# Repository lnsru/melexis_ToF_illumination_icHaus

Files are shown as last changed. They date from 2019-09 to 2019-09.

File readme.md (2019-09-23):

# Illumination board

This board to be used with time of flight camera. There are interesting chips from Melexis, Infineon, TI and Sony. [My another repository](https://github.com/lnsru/melexis_VGA_ToF_camera "VGA time of flight camera") contains design with Melexis VGA resolution time of flight sensor.

[Higly integrated chip from iC-Haus](http://www.ichaus.de/product/iC-HGP "iC-HGP") was choosen for simpler design. It is specialized high current high speed swich for applications like this one. Buy some from [iC-Haus USA shop.](https://us-shop.ichaus.com/ProductDetails.asp?ProductCode=iC%2DHGP "Buy iC-HGP") 

The design should work with LEDs from Osram and Lumileds. Check datasheet for needed exact voltage, I assume, it will work with 10-12 V power supply.

Following parts are supported:
* Lumileds L1IG-0850000000000 (assembled on prototype board)
* Lumileds L1IG-0940000000000
* Osram SFH 4770S
* Osram SFH 4775S

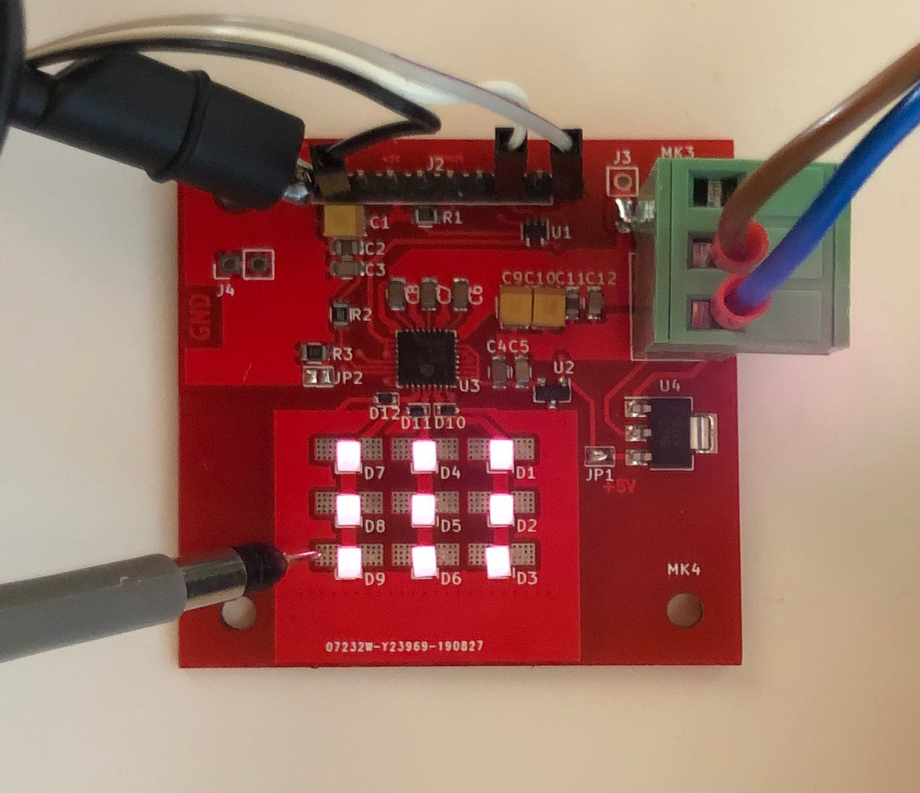
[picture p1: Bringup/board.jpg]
LEDs on


Note: modern phones have infrared filters and can't take nice photos. The glowing red is LED illumination in visible spectrum. The pulses were seen with iPhone 3G and oscilloscope.

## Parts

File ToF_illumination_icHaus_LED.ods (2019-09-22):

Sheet: ToF_illumination_bw
Reference | Quantity | Value | Footprint | Datasheet
C10 C1 | 2 | 10u | Capacitors_SMD:C_1210 | Tantalum!!!
C11 C2 | 2 | 100n | Capacitors_SMD:C_0805 | ~
C12 C3 C5 | 3 | 10n | Capacitors_SMD:C_0805 | ~
C4 C6 C7 C8 | 4 | 1u | Capacitors_SMD:C_0805 | ~
C9 | 1 | 100u | Capacitors_SMD:C_1210 | ~
D12 D11 D10 | 3 | uClamp1201H | Diodes_SMD:D_SOD-523 | https://eu.mouser.com/ProductDetail/Semtech/UCLAMP1201HTCT | UCLAMP1201H.TCT
D8 D7 D9 D5 D4 D6 D2 D1 D3 | 9 | LED | myFootprints:LuxeonIR2720_singlePad | https://eu.mouser.com/ProductDetail/Lumileds/L1IG-0850000000000 | L1IG-0850000000000
J1 | 1 | Screw_Terminal_01x02 | Connectors_Terminal_Blocks:TerminalBlock_bornier-2_P5.08mm | ~
J2 | 1 | Conn_01x10 | Pin_Headers:Pin_Header_Straight_1x10_Pitch2.54mm | ~
J4 J3 | 2 | Conn_01x02 | Pin_Headers:Pin_Header_Straight_1x02_Pitch2.54mm | ~
JP1 JP2 | 2 | SolderJumper_2_Open | Connectors:GS2 | ~
MK1 MK2 MK3 MK4 | 4 | Mounting_Hole | Mounting_Holes:MountingHole_3.2mm_M3_ISO7380
R1 | 1 | 10k | Resistors_SMD:R_0805 | ~
R2 | 1 | 7.5k | Resistors_SMD:R_0805 | ~
R3 | 1 | 3.32k | Resistors_SMD:R_0805 | ~
U1 | 1 | SN74AUP1T34DCK | TO_SOT_Packages_SMD:SOT-353_SC-70-5 | http://www.ti.com/lit/ds/symlink/sn74aup1t34.pdf
U2 | 1 | MCP1541-TT | TO_SOT_Packages_SMD:SOT-23 | http://ww1.microchip.com/downloads/en/devicedoc/21653b.pdf
U3 | 1 | iC-HGP | myFootprints:QFN_32_5x5mm_0.5mm_thermal | https://ichaus.de/upload/pdf/HGP_datasheet_A2en.pdf
U4 | 1 | LM2937xT | TO_SOT_Packages_SMD:SOT-223 | http://www.ti.com/lit/ds/symlink/lm2937.pdf | LM2937IMP-5.0/NOPB

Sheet: ToF_illumination_icHaus_LED
Reference | Quantity | Value | Footprint | Datasheet
C10 C1 | 2 | 10u | Capacitors_SMD:C_1210 | Tantalum!!!
C11 C2 | 2 | 100n | Capacitors_SMD:C_0805 | ~
C12 C3 C5 | 3 | 10n | Capacitors_SMD:C_0805 | ~
C4 C6 C7 C8 | 4 | 1u | Capacitors_SMD:C_0805 | ~
C9 | 1 | 100u | Capacitors_SMD:C_1210 | ~
D12 D11 D10 | 3 | uClamp1201H | Diodes_SMD:D_SOD-523 | https://eu.mouser.com/ProductDetail/Semtech/UCLAMP1201HTCT | UCLAMP1201H.TCT
D8 D7 D9 D5 D4 D6 D2 D1 D3 | 9 | LED | myFootprints:LuxeonIR2720_singlePad | https://eu.mouser.com/ProductDetail/Lumileds/L1IG-0850000000000 | L1IG-0850000000000
J1 | 1 | Screw_Terminal_01x02 | Connectors_Terminal_Blocks:TerminalBlock_bornier-2_P5.08mm | ~
J2 | 1 | Conn_01x10 | Pin_Headers:Pin_Header_Straight_1x10_Pitch2.54mm | ~
J4 J3 | 2 | Conn_01x02 | Pin_Headers:Pin_Header_Straight_1x02_Pitch2.54mm | ~
JP1 JP2 | 2 | SolderJumper_2_Open | Connectors:GS2 | ~
MK1 MK2 MK3 MK4 | 4 | Mounting_Hole | Mounting_Holes:MountingHole_3.2mm_M3_ISO7380
R1 | 1 | 10k | Resistors_SMD:R_0805 | ~
R2 | 1 | 7.5k | Resistors_SMD:R_0805 | ~
R3 | 1 | 3.32k | Resistors_SMD:R_0805 | ~
U1 | 1 | SN74AUP1T34DCK | TO_SOT_Packages_SMD:SOT-353_SC-70-5 | http://www.ti.com/lit/ds/symlink/sn74aup1t34.pdf
U2 | 1 | MCP1541-TT | TO_SOT_Packages_SMD:SOT-23 | http://ww1.microchip.com/downloads/en/devicedoc/21653b.pdf
U3 | 1 | iC-HGP | myFootprints:QFN_32_5x5mm_0.5mm_thermal | https://ichaus.de/upload/pdf/HGP_datasheet_A2en.pdf
U4 | 1 | LM2937xT | TO_SOT_Packages_SMD:SOT-223 | http://www.ti.com/lit/ds/symlink/lm2937.pdf | LM2937IMP-5.0/NOPB

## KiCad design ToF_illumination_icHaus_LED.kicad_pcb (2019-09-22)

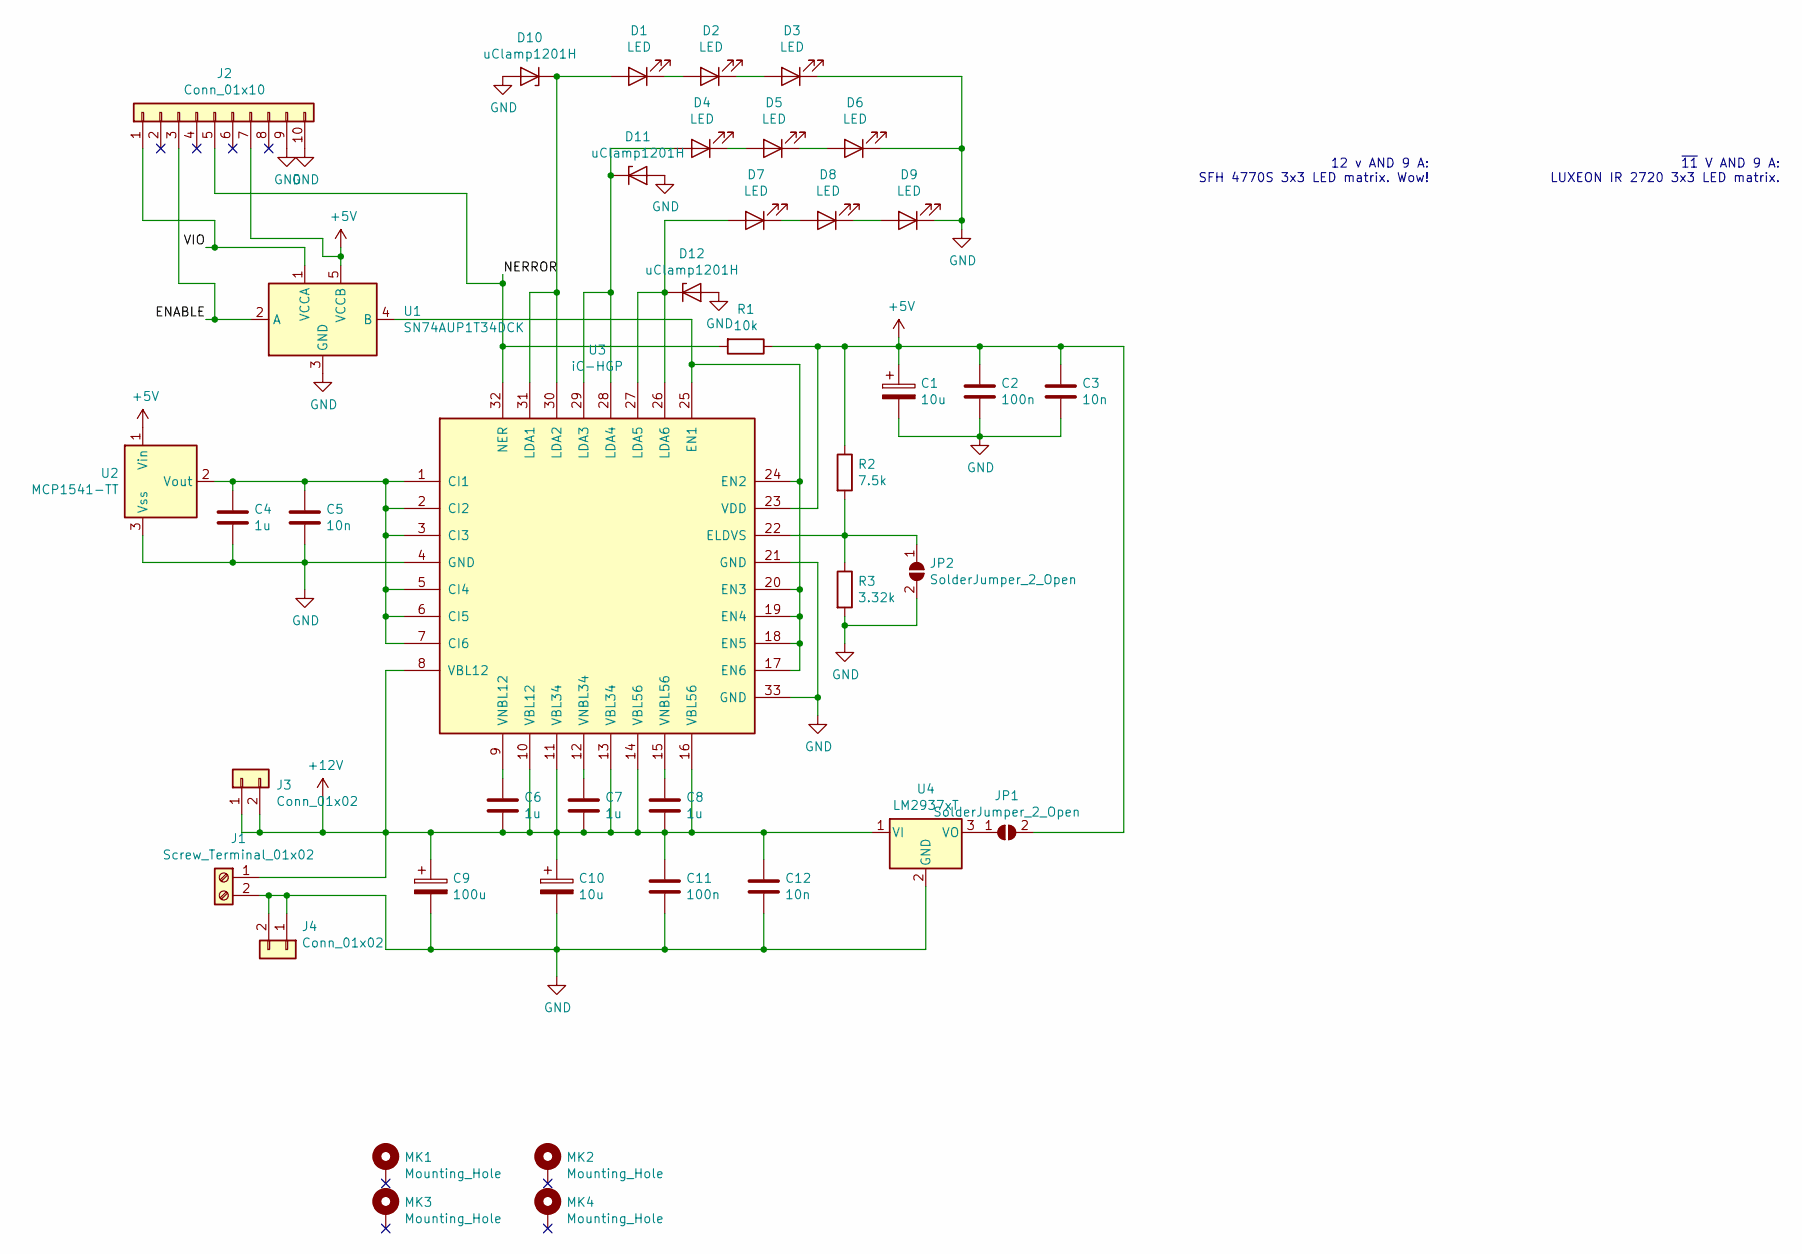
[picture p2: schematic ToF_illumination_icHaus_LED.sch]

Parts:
C1, C10: 10u; C_1210
C2, C11: 100n; C_0805
C3, C5, C12: 10n; C_0805
C4, C6, C7, C8: 1u; C_0805
C9: 100u; C_1210
D1, D2, D3, D4, D5, D6, D7, D8, D9: LED; LuxeonIR2720_singlePad
D10, D11, D12: uClamp1201H; D_SOD-523
J1: Screw_Terminal_01x02; TerminalBlock_bornier-2_P5.08mm
J2: Conn_01x10; Pin_Header_Straight_1x10_Pitch2.54mm
J3, J4: Conn_01x02; Pin_Header_Straight_1x02_Pitch2.54mm
JP1, JP2: SolderJumper_2_Open; GS2
MK1, MK2, MK3, MK4: Mounting_Hole; MountingHole_3.2mm_M3_ISO7380
R1: 10k; R_0805
R2: 7.5k; R_0805
R3: 3.32k; R_0805
U1: SN74AUP1T34DCK; SOT-353_SC-70-5
U2: MCP1541-TT; SOT-23
U3: iC-HGP; QFN_32_5x5mm_0.5mm_thermal
U4: LM2937xT; SOT-223

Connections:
+5V: C1.1, C2.1, C3.1, J2.7, JP1.2 (B), R1.1, R2.1, U1.5 (VCCB), U2.1 (Vin), U3.23 (VDD)
+12V: C6.1, C7.1, C8.1, C9.1, C10.1, C11.1, C12.1, J1.1, J3.1, J3.2, U3.8 (VBL12), U3.10 (VBL12), U3.11 (VBL34), U3.13 (VBL34), U3.14 (VBL56), U3.16 (VBL56), U4.1 (VI)
/ENABLE: J2.3, U1.2 (A)
/NERROR: J2.5, R1.2, U3.32 (NER)
/VIO: J2.1, U1.1 (VCCA)
GND: C1.2, C2.2, C3.2, C4.2, C5.2, C9.2, C10.2, C11.2, C12.2, D3.1 (K), D6.1 (K), D9.1 (K), D10.2 (A), D11.2 (A), D12.2 (A), J1.2, J2.9, J2.10, J4.1, J4.2, JP2.2 (B), R3.2, U1.3 (GND), U2.3 (Vss), U3.4 (GND), U3.21 (GND), U3.33 (GND), U4.2 (GND)
unnamed: C4.1, C5.1, U2.2 (Vout), U3.1 (CI1), U3.2 (CI2), U3.3 (CI3), U3.5 (CI4), U3.6 (CI5), U3.7 (CI6)
unnamed: C6.2, U3.9 (VNBL12)
unnamed: C7.2, U3.12 (VNBL34)
unnamed: C8.2, U3.15 (VNBL56)
unnamed: D1.1 (K), D2.2 (A)
unnamed: D1.2 (A), D10.1 (K), U3.30 (LDA2), U3.31 (LDA1)
unnamed: D2.1 (K), D3.2 (A)
unnamed: D4.1 (K), D5.2 (A)
unnamed: D5.1 (K), D6.2 (A)
unnamed: D7.1 (K), D8.2 (A)
unnamed: D8.1 (K), D9.2 (A)
unnamed: D4.2 (A), D11.1 (K), U3.28 (LDA4), U3.29 (LDA3)
unnamed: D7.2 (A), D12.1 (K), U3.26 (LDA6), U3.27 (LDA5)
unnamed: JP1.1 (A), U4.3 (VO)
unnamed: JP2.1 (A), R2.2, R3.1, U3.22 (ELDVS)
unnamed: U1.4 (B), U3.17 (EN6), U3.18 (EN5), U3.19 (EN4), U3.20 (EN3), U3.24 (EN2), U3.25 (EN1)

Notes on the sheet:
12 v AND 9 A: SFH 4770S 3x3 LED matrix. Wow!
~11 V AND 9 A: LUXEON IR 2720 3x3 LED matrix.

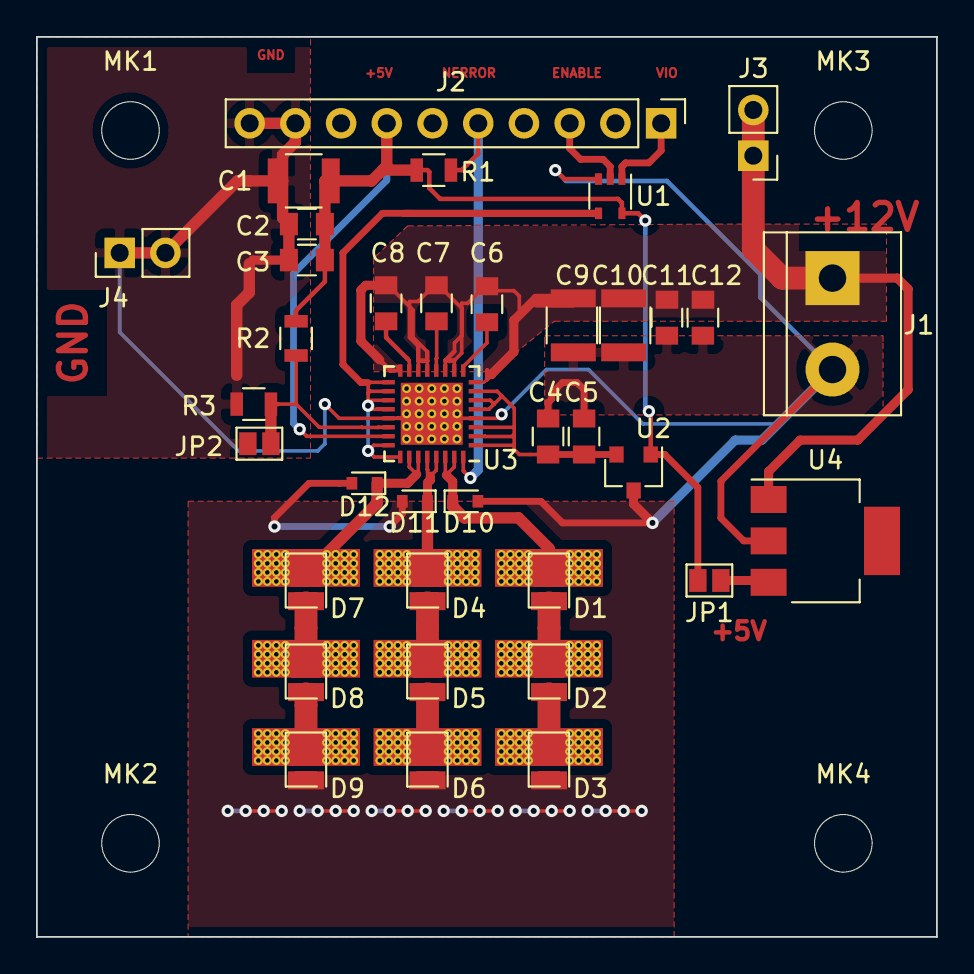
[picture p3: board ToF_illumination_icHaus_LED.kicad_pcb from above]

Board: 2 copper layers, 50.0 x 50.0 mm, 41 parts (0 on the bottom side), 22 nets.

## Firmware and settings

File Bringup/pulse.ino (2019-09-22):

int voltagePin = 12;
int enablePin = 13;



void setup() 
{
    Serial.begin(9600);
    Serial.print("Online");   
 
    pinMode(enablePin, OUTPUT);  
    digitalWrite(enablePin,LOW); 

    pinMode(voltagePin, OUTPUT);  
    digitalWrite(voltagePin, HIGH); 


}
 
void loop()
{
  delay(10) ; 
  digitalWrite(enablePin, HIGH);
  delay(1) ;
  digitalWrite(enablePin, LOW);
}

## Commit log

2019-08-20 Tantalum capacitors were changed to 1210 size and project was moved to KiCad 5.1.4
    [ToF_illumination_icHaus_LED.kicad_pcb, ToF_illumination_icHaus_LED.sch]
2019-08-20 Added BOM, improved footprints a bit.
    [ToF_illumination_icHaus_LED.kicad_pcb, ToF_illumination_icHaus_LED.ods, ToF_illumination_icHaus_LED.sch]
2019-08-21 Updated BOM
    [ToF_illumination_icHaus_LED.ods]
2019-08-25 Gerbers added and some labels on the board for assembly added
    [ToF_illumination_icHaus_LED.kicad_pcb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]
2019-09-22 Looks like, this design is working!
    [ToF_illumination_icHaus_LED.kicad_pcb, ToF_illumination_icHaus_LED.ods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]
